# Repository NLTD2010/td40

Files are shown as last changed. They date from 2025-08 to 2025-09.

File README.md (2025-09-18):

# TD40



> **TD40** is a compact 40% mechanical keyboard designed for efficiency and portability.  
> It features **hot-swappable switches**, a **rotary knob**, an **OLED display**, **wireless connectivity**, and **per-key RGB lighting**.

---

## 🖼️ Preview

| TD40 (Back) | PCB |
|---|-----|
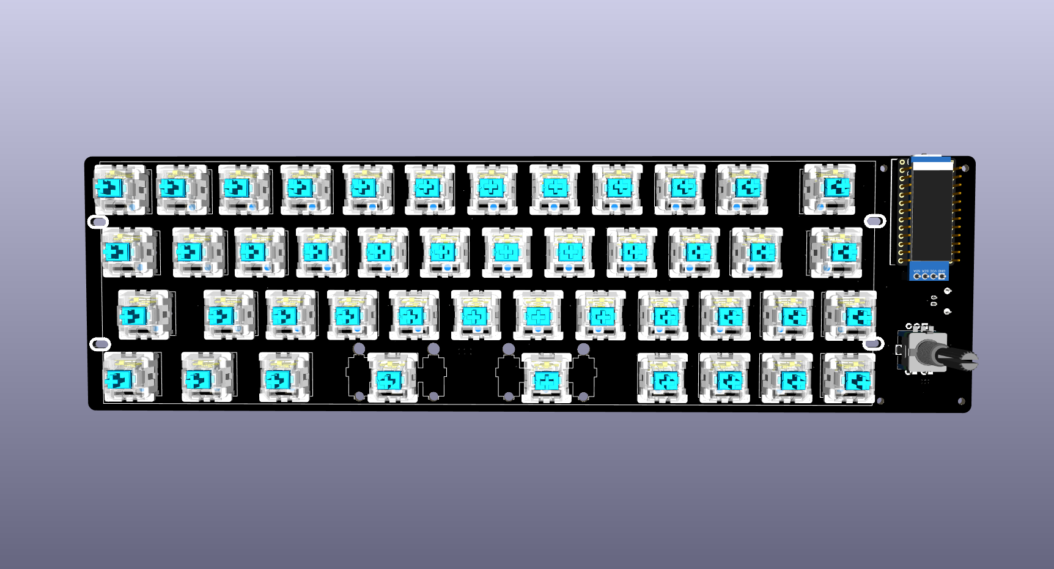
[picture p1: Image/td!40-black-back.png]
td40
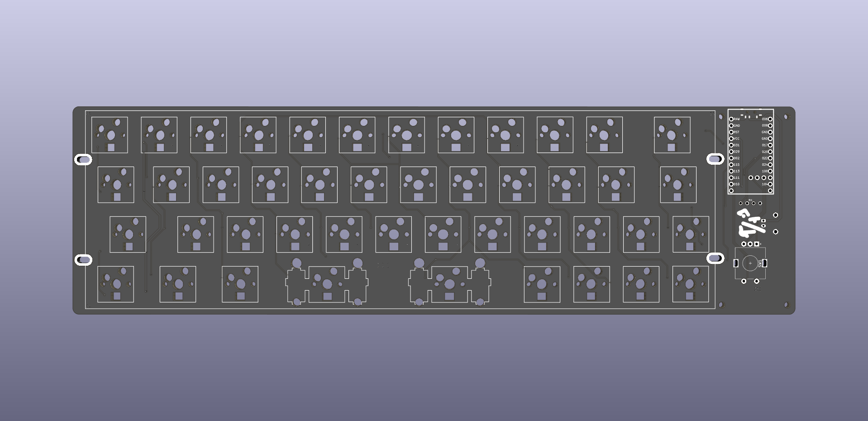
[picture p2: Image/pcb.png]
pcb
|  |  |

---

## ✨ Features
- Clean PCB design with **SMD soldering**
- **Nice!Nano v2** microcontroller – USB-C & Bluetooth compatible
- **Rotary encoder** + knob
- **0.91" OLED** screen
- **Per-key RGB** lighting
- **Hot-swappable** switches
- Open & visible components (Plaid / Romac style)
- Simple, flexible case options

---

## ⌨️ Layout
layout

---

## 📦 Bill of Materials

| # | Item | Qty |
|---|---|----:|
| 1 | PCB | 1 |
| 2 | FR4 plate | 1 |
| 3 | Mica case | 1 |
| 4 | Controller (**Nice!Nano v2**) | 1 |
| 5 | Switches (5-pin MX footprint)| 45 |
| 6 | Kailh hotswap socket | 45 |
| 7 | Diodes | 46 |
| 8 | Rotary encoder & knob | 1 |
| 9 | 0.91" OLED screen | 1 |

---

💡 **Tip:** Check out the [repository](https://github.com/NLTD2010/td40) for firmware, build guide, and more!

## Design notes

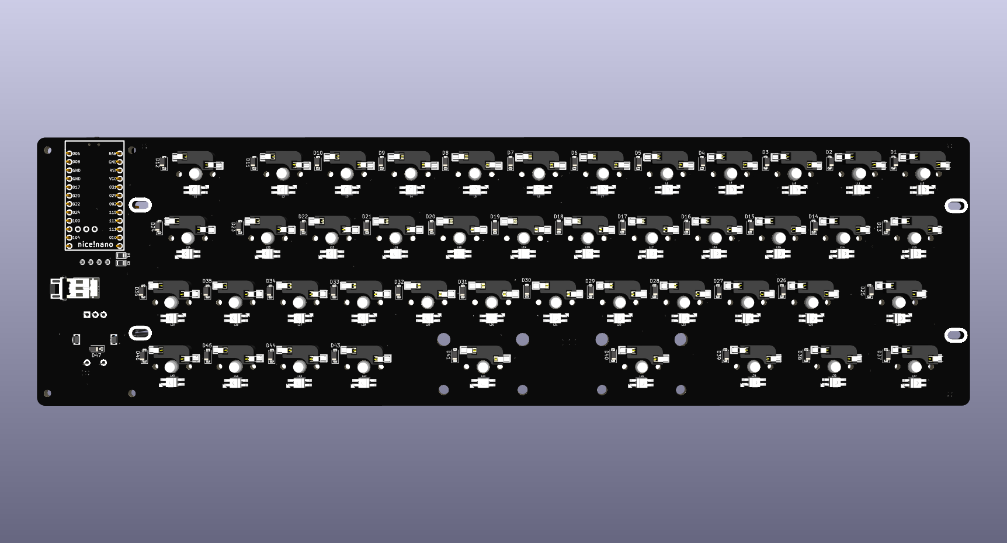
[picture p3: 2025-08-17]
Image/td!40-back-black.png

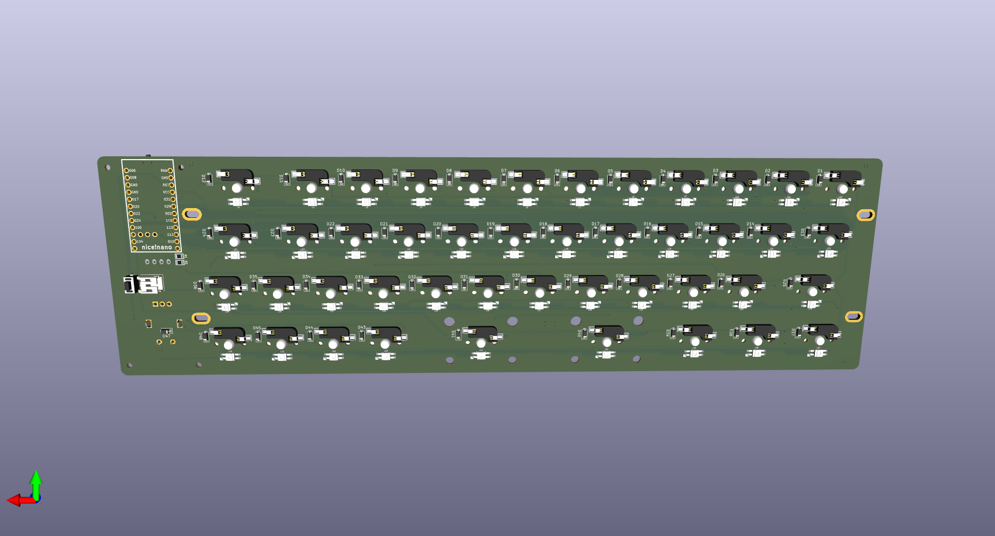
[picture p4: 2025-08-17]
Image/td!40_back.png

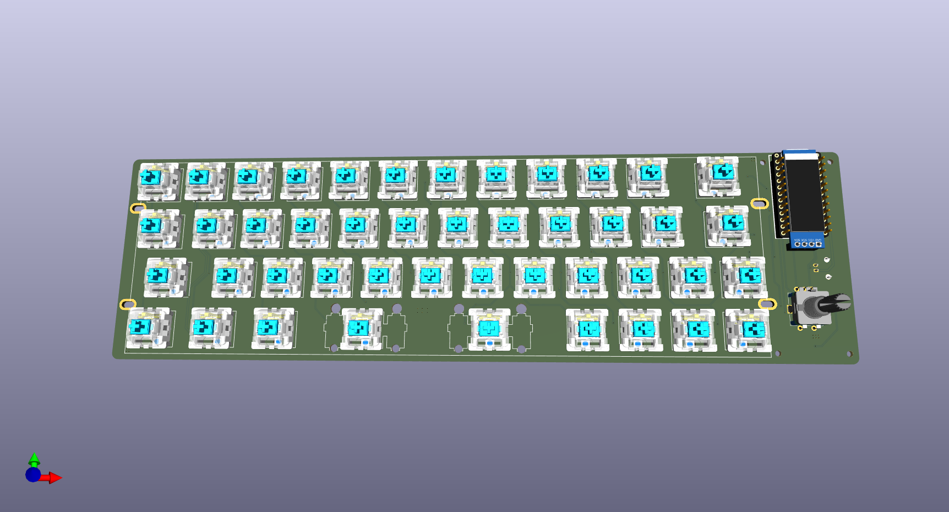
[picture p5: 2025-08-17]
Image/td!40.png

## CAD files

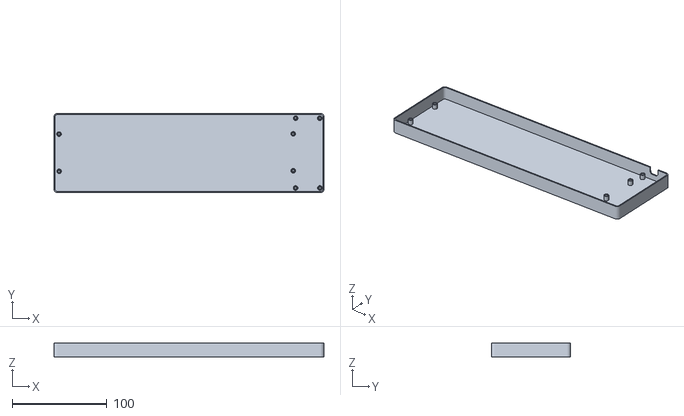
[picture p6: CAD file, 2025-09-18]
Case/case.stl
284.5 x 83.7 x 14.5

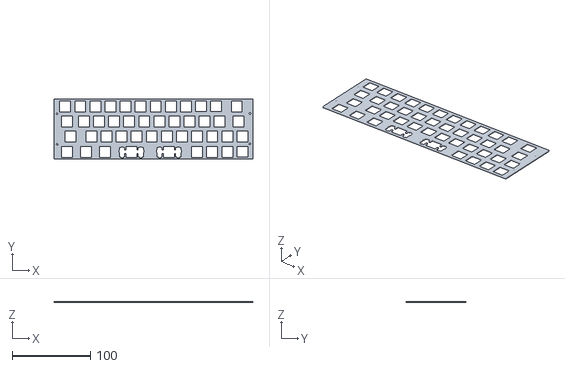
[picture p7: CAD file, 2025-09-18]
Case/plate.stl
254.5 x 76.9 x 1.51

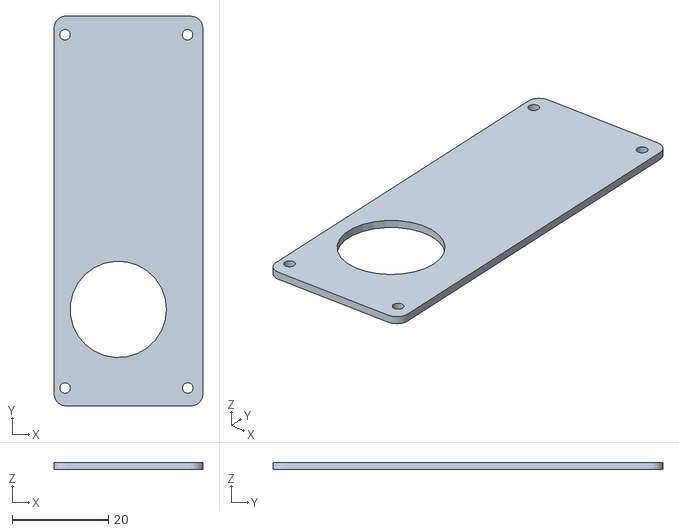
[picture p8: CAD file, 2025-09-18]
Case/cover.stl
31.0 x 81.2 x 1.51

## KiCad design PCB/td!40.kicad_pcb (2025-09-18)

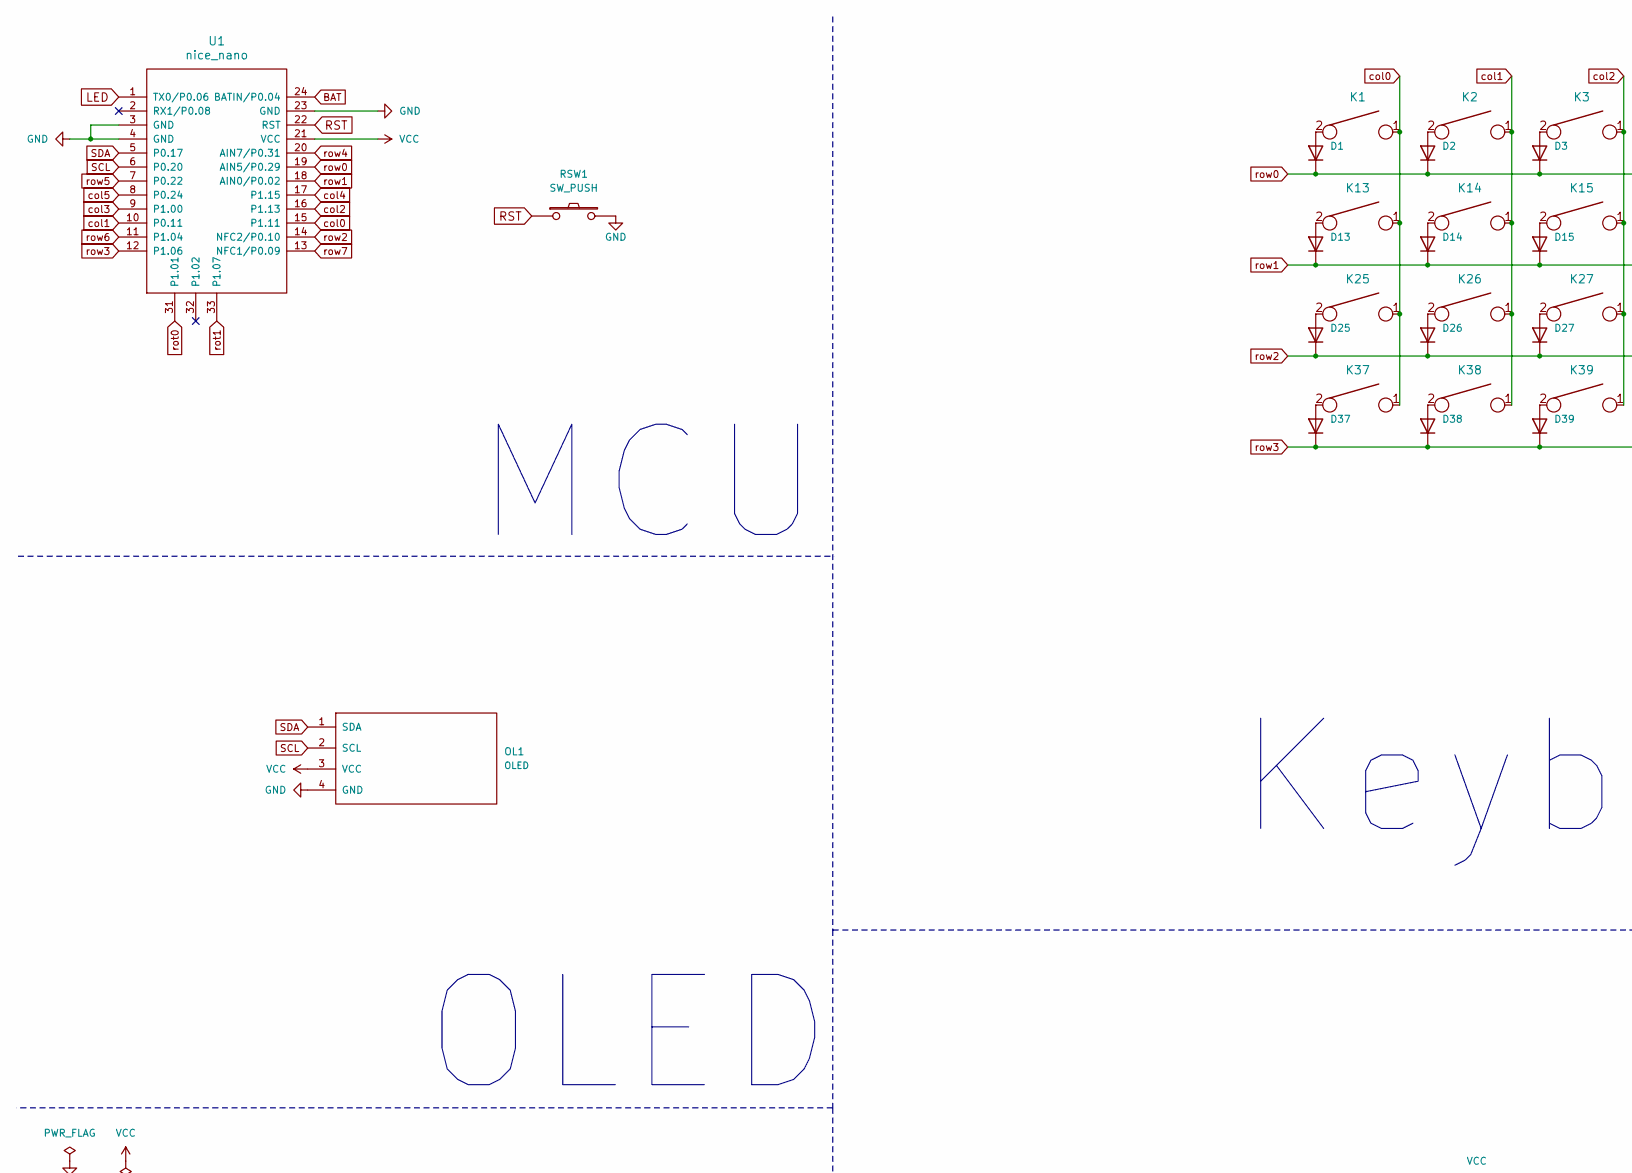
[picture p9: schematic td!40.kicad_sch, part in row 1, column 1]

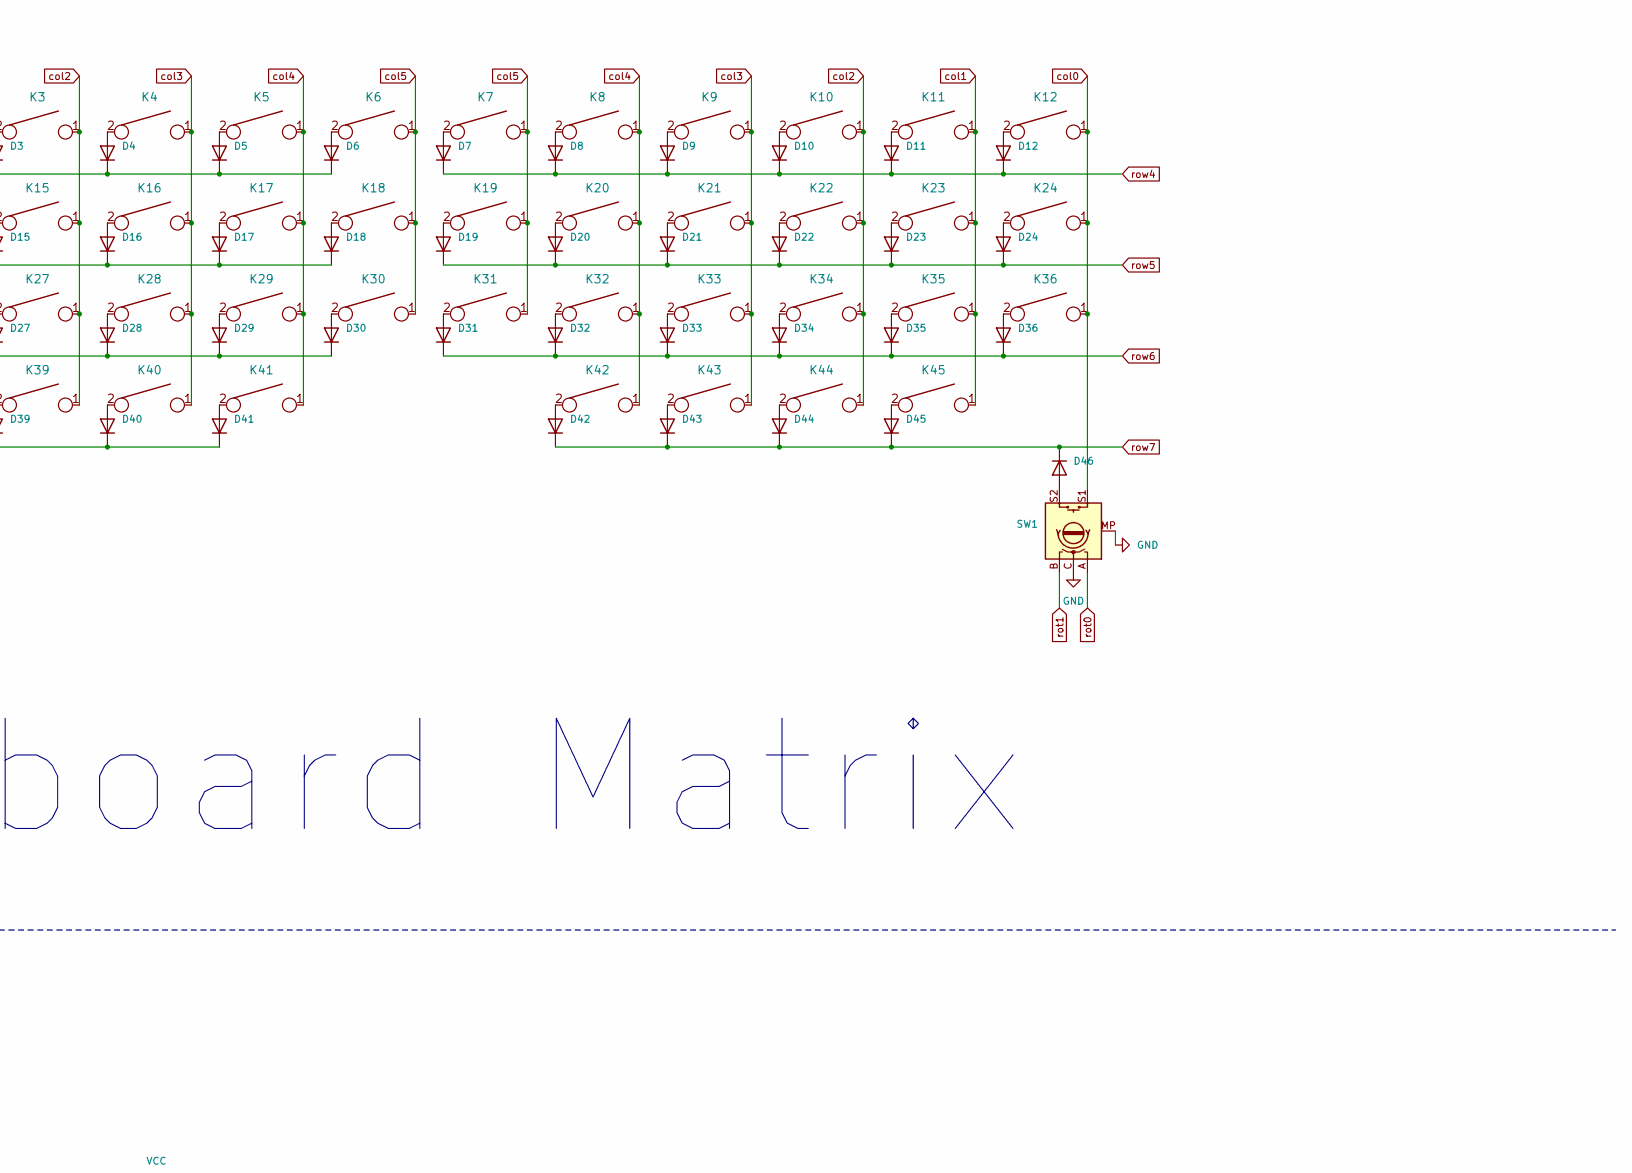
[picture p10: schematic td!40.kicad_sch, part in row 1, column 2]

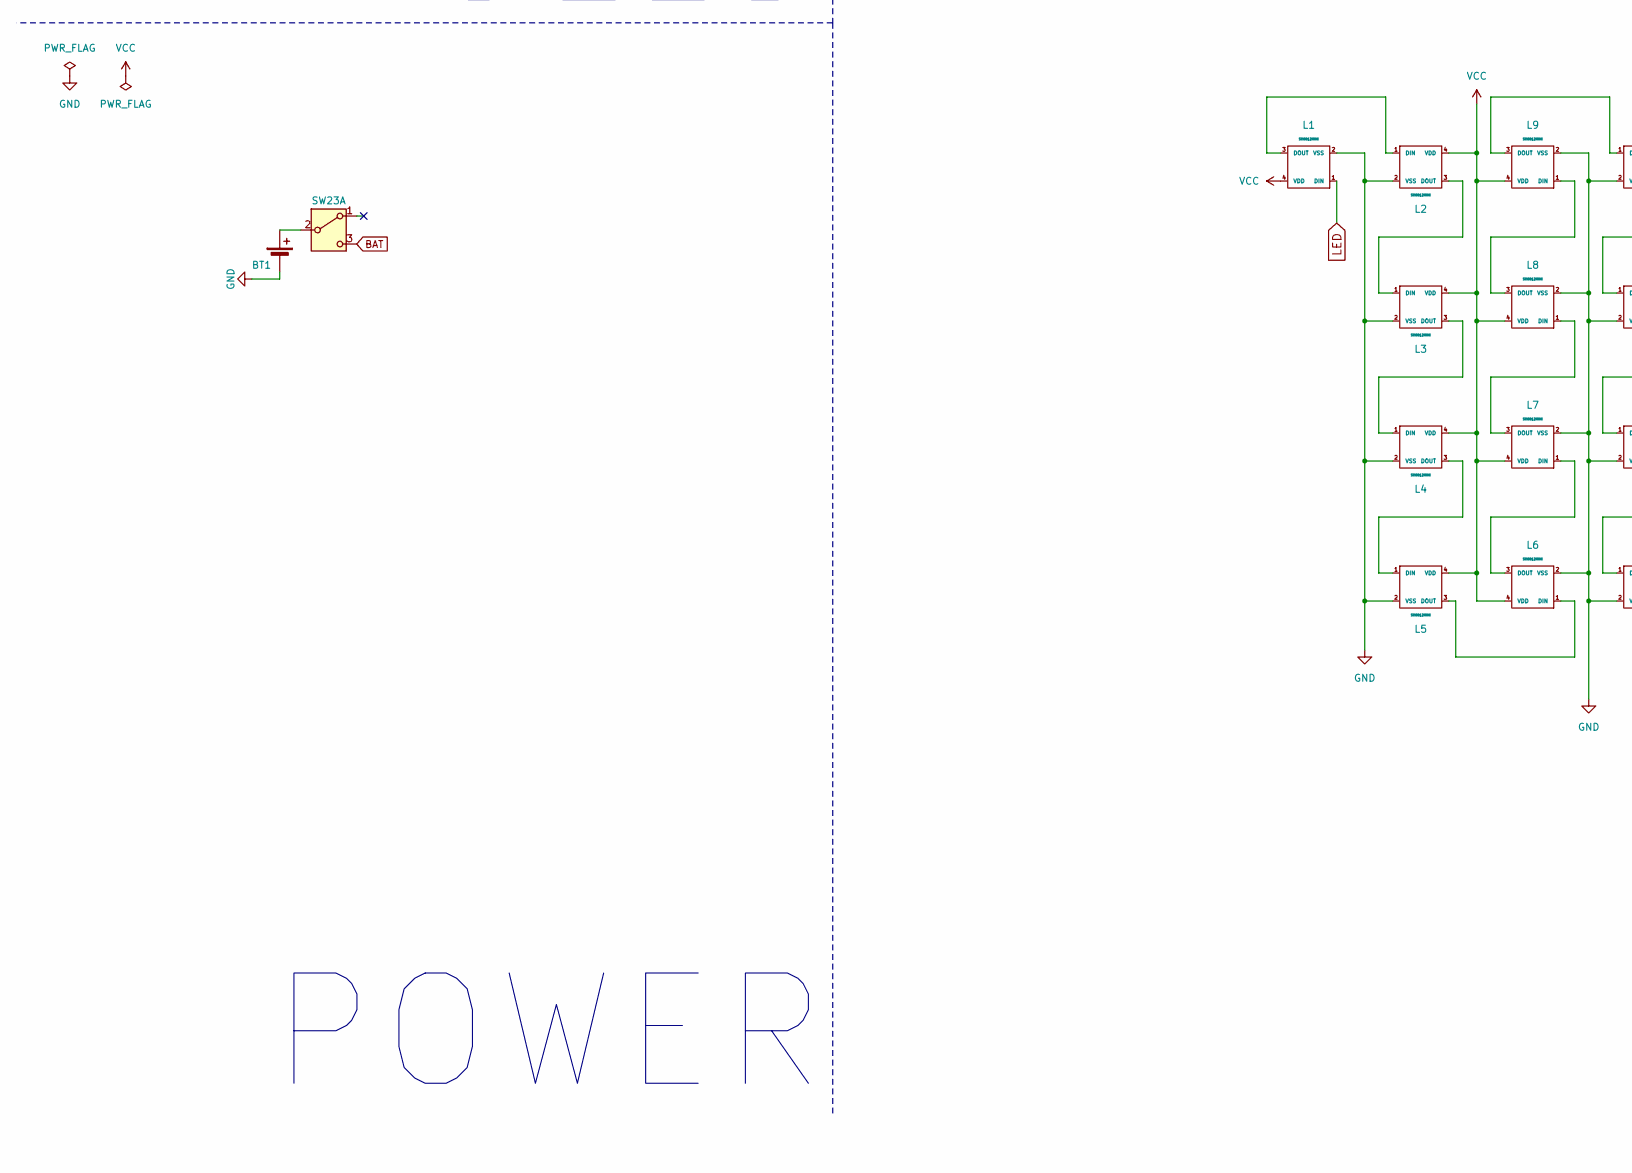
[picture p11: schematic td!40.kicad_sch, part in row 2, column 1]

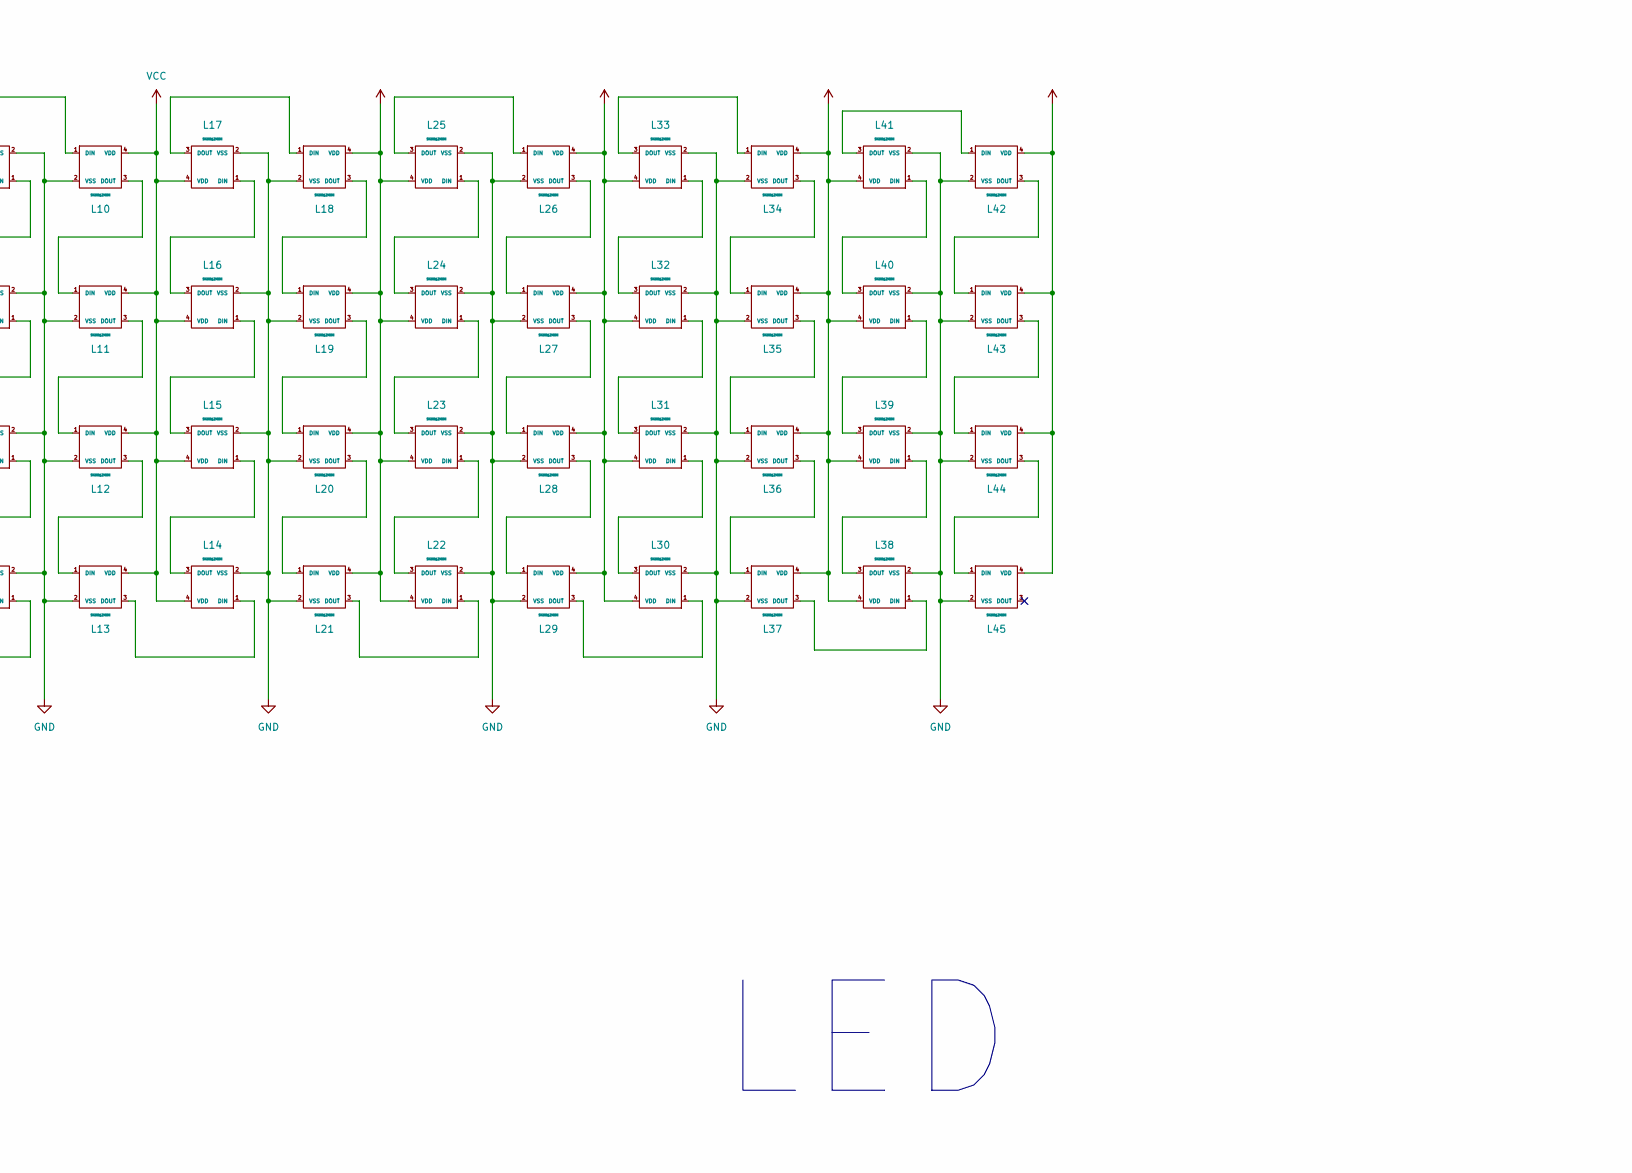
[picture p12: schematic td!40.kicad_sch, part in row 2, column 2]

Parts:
BT1: Battery_Cell; JST_PH_S2B-PH-K_1x02_P2.00mm_Horizontal_flipped
D1, D2, D3, D4, D5, D6, D7, D8, D9, D10, D11, D12, D13, D14, D15, D16, D17, D18, D19, D20, D21, D22, D23, D24, D25, D26, D27, D28, D29, D30, D31, D32, D33, D34, D35, D36, D37, D38, D39, D40, D41, D42, D43, D44, D45: D_SOD-123
D46: D; D_SOD-123
K1, K2, K3, K4, K5, K6, K7, K8, K9, K10, K11, K14, K15, K16, K17, K18, K19, K20, K21, K22, K23, K26, K27, K28, K29, K30, K31, K32, K33, K34, K35, K36, K42, K43, K44, K45: KEYSW; MX-Hotswap-1U
K12, K25: KEYSW; MX-Hotswap-1.75U
K13, K37, K38, K39: KEYSW; MX-Hotswap-1.25U
K24: KEYSW; MX-Hotswap-1.5U
K40: KEYSW; MX-Hotswap-2.25U-ReversedStabilizers
K41: KEYSW; MX-Hotswap-2.75U-ReversedStabilizers
L1, L2, L3, L4, L5, L6, L7, L8, L9, L10, L11, L12, L13, L14, L15, L16, L17, L18, L19, L20, L21, L22, L23, L24, L25, L26, L27, L28, L29, L30, L31, L32, L33, L34, L35, L36, L37, L38, L39, L40, L41, L42, L43, L44, L45: SK6812MINI; YS-SK6812MINI-E
OL1: OLED
RSW1: SW_PUSH; ResetSW
SW1: RotaryEncoder_Switch; RotaryEncoder_Alps_EC11E-Switch_Vertical_H20mm
SW23: SW23; switch-MSK-12C02-smd
U1: nice_nano

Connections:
BAT: SW23.3 (C), U1.24 (BATIN/P0.04)
GND: BT1.2 (-), L1.2 (VSS), L2.2 (VSS), L3.2 (VSS), L4.2 (VSS), L5.2 (VSS), L6.2 (VSS), L7.2 (VSS), L8.2 (VSS), L9.2 (VSS), L10.2 (VSS), L11.2 (VSS), L12.2 (VSS), L13.2 (VSS), L14.2 (VSS), L15.2 (VSS), L16.2 (VSS), L17.2 (VSS), L18.2 (VSS), L19.2 (VSS), L20.2 (VSS), L21.2 (VSS), L22.2 (VSS), L23.2 (VSS), L24.2 (VSS), L25.2 (VSS), L26.2 (VSS), L27.2 (VSS), L28.2 (VSS), L29.2 (VSS), L30.2 (VSS), L31.2 (VSS), L32.2 (VSS), L33.2 (VSS), L34.2 (VSS), L35.2 (VSS), L36.2 (VSS), L37.2 (VSS), L38.2 (VSS), L39.2 (VSS), L40.2 (VSS), L41.2 (VSS), L42.2 (VSS), L43.2 (VSS), L44.2 (VSS), L45.2 (VSS), OL1.4 (GND), RSW1.2, SW1.C, SW1.MP, U1.3 (GND), U1.4 (GND), U1.23 (GND)
LED: L1.1 (DIN), U1.1 (TX0/P0.06)
unnamed: BT1.1 (+), SW23.2 (B)
unnamed: D1.2 (A), K1.2
unnamed: D2.2 (A), K2.2
unnamed: D3.2 (A), K3.2
unnamed: D4.2 (A), K4.2
unnamed: D5.2 (A), K5.2
unnamed: D6.2 (A), K6.2
unnamed: D7.2 (A), K7.2
unnamed: D8.2 (A), K8.2
unnamed: D9.2 (A), K9.2
unnamed: D10.2 (A), K10.2
unnamed: D11.2 (A), K11.2
unnamed: D12.2 (A), K12.2
unnamed: D13.2 (A), K13.2
unnamed: D14.2 (A), K14.2
unnamed: D15.2 (A), K15.2
unnamed: D16.2 (A), K16.2
unnamed: D17.2 (A), K17.2
unnamed: D18.2 (A), K18.2
unnamed: D19.2 (A), K19.2
unnamed: D20.2 (A), K20.2
unnamed: D21.2 (A), K21.2
unnamed: D22.2 (A), K22.2
unnamed: D23.2 (A), K23.2
unnamed: D24.2 (A), K24.2
unnamed: D25.2 (A), K25.2
unnamed: D26.2 (A), K26.2
unnamed: D27.2 (A), K27.2
unnamed: D28.2 (A), K28.2
unnamed: D29.2 (A), K29.2
unnamed: D30.2 (A), K30.2
unnamed: D31.2 (A), K31.2
unnamed: D32.2 (A), K32.2
unnamed: D33.2 (A), K33.2
unnamed: D34.2 (A), K34.2
unnamed: D35.2 (A), K35.2
unnamed: D36.2 (A), K36.2
unnamed: D37.2 (A), K37.2
unnamed: D38.2 (A), K38.2
unnamed: D39.2 (A), K39.2
unnamed: D40.2 (A), K40.2
unnamed: D41.2 (A), K41.2
unnamed: D42.2 (A), K42.2
unnamed: D43.2 (A), K43.2
unnamed: D44.2 (A), K44.2
unnamed: D45.2 (A), K45.2
unnamed: D46.2 (A), SW1.S2
unnamed: L1.3 (DOUT), L2.1 (DIN)
unnamed: L2.3 (DOUT), L3.1 (DIN)
unnamed: L3.3 (DOUT), L4.1 (DIN)
unnamed: L4.3 (DOUT), L5.1 (DIN)
unnamed: L5.3 (DOUT), L6.1 (DIN)
unnamed: L6.3 (DOUT), L7.1 (DIN)
unnamed: L7.3 (DOUT), L8.1 (DIN)
unnamed: L8.3 (DOUT), L9.1 (DIN)
unnamed: L9.3 (DOUT), L10.1 (DIN)
unnamed: L10.3 (DOUT), L11.1 (DIN)
unnamed: L11.3 (DOUT), L12.1 (DIN)
unnamed: L12.3 (DOUT), L13.1 (DIN)
unnamed: L13.3 (DOUT), L14.1 (DIN)
unnamed: L14.3 (DOUT), L15.1 (DIN)
unnamed: L15.3 (DOUT), L16.1 (DIN)
unnamed: L16.3 (DOUT), L17.1 (DIN)
unnamed: L17.3 (DOUT), L18.1 (DIN)
unnamed: L18.3 (DOUT), L19.1 (DIN)
unnamed: L19.3 (DOUT), L20.1 (DIN)
unnamed: L20.3 (DOUT), L21.1 (DIN)
unnamed: L21.3 (DOUT), L22.1 (DIN)
unnamed: L22.3 (DOUT), L23.1 (DIN)
unnamed: L23.3 (DOUT), L24.1 (DIN)
unnamed: L24.3 (DOUT), L25.1 (DIN)
unnamed: L25.3 (DOUT), L26.1 (DIN)
unnamed: L26.3 (DOUT), L27.1 (DIN)
unnamed: L27.3 (DOUT), L28.1 (DIN)
unnamed: L28.3 (DOUT), L29.1 (DIN)
unnamed: L29.3 (DOUT), L30.1 (DIN)
unnamed: L30.3 (DOUT), L31.1 (DIN)
unnamed: L31.3 (DOUT), L32.1 (DIN)
unnamed: L32.3 (DOUT), L33.1 (DIN)
unnamed: L33.3 (DOUT), L34.1 (DIN)
unnamed: L34.3 (DOUT), L35.1 (DIN)
unnamed: L35.3 (DOUT), L36.1 (DIN)
unnamed: L36.3 (DOUT), L37.1 (DIN)
unnamed: L37.3 (DOUT), L38.1 (DIN)
unnamed: L38.3 (DOUT), L39.1 (DIN)
unnamed: L39.3 (DOUT), L40.1 (DIN)
unnamed: L40.3 (DOUT), L41.1 (DIN)
unnamed: L41.3 (DOUT), L42.1 (DIN)
unnamed: L42.3 (DOUT), L43.1 (DIN)
unnamed: L43.3 (DOUT), L44.1 (DIN)
unnamed: L44.3 (DOUT), L45.1 (DIN)
RST: RSW1.1, U1.22 (RST)
SCL: OL1.2 (SCL), U1.6 (P0.20)
SDA: OL1.1 (SDA), U1.5 (P0.17)
VCC: L1.4 (VDD), L2.4 (VDD), L3.4 (VDD), L4.4 (VDD), L5.4 (VDD), L6.4 (VDD), L7.4 (VDD), L8.4 (VDD), L9.4 (VDD), L10.4 (VDD), L11.4 (VDD), L12.4 (VDD), L13.4 (VDD), L14.4 (VDD), L15.4 (VDD), L16.4 (VDD), L17.4 (VDD), L18.4 (VDD), L19.4 (VDD), L20.4 (VDD), L21.4 (VDD), L22.4 (VDD), L23.4 (VDD), L24.4 (VDD), L25.4 (VDD), L26.4 (VDD), L27.4 (VDD), L28.4 (VDD), L29.4 (VDD), L30.4 (VDD), L31.4 (VDD), L32.4 (VDD), L33.4 (VDD), L34.4 (VDD), L35.4 (VDD), L36.4 (VDD), L37.4 (VDD), L38.4 (VDD), L39.4 (VDD), L40.4 (VDD), L41.4 (VDD), L42.4 (VDD), L43.4 (VDD), L44.4 (VDD), L45.4 (VDD), OL1.3 (VCC), U1.21 (VCC)
col0: K1.1, K12.1, K13.1, K24.1, K25.1, K36.1, K37.1, SW1.S1, U1.15 (P1.11)
col1: K2.1, K11.1, K14.1, K23.1, K26.1, K35.1, K38.1, K45.1, U1.10 (P0.11)
col2: K3.1, K10.1, K15.1, K22.1, K27.1, K34.1, K39.1, K44.1, U1.16 (P1.13)
col3: K4.1, K9.1, K16.1, K21.1, K28.1, K33.1, K40.1, K43.1, U1.9 (P1.00)
col4: K5.1, K8.1, K17.1, K20.1, K29.1, K32.1, K41.1, K42.1, U1.17 (P1.15)
col5: K6.1, K7.1, K18.1, K19.1, K30.1, K31.1, U1.8 (P0.24)
rot0: SW1.A, U1.31 (P1.01)
rot1: SW1.B, U1.33 (P1.07)
row0: D1.1 (K), D2.1 (K), D3.1 (K), D4.1 (K), D5.1 (K), D6.1 (K), U1.19 (AIN5/P0.29)
row1: D13.1 (K), D14.1 (K), D15.1 (K), D16.1 (K), D17.1 (K), D18.1 (K), U1.18 (AIN0/P0.02)
row2: D25.1 (K), D26.1 (K), D27.1 (K), D28.1 (K), D29.1 (K), D30.1 (K), U1.14 (NFC2/P0.10)
row3: D37.1 (K), D38.1 (K), D39.1 (K), D40.1 (K), D41.1 (K), U1.12 (P1.06)
row4: D7.1 (K), D8.1 (K), D9.1 (K), D10.1 (K), D11.1 (K), D12.1 (K), U1.20 (AIN7/P0.31)
row5: D19.1 (K), D20.1 (K), D21.1 (K), D22.1 (K), D23.1 (K), D24.1 (K), U1.7 (P0.22)
row6: D31.1 (K), D32.1 (K), D33.1 (K), D34.1 (K), D35.1 (K), D36.1 (K), U1.11 (P1.04)
row7: D42.1 (K), D43.1 (K), D44.1 (K), D45.1 (K), D46.1 (K), U1.13 (NFC1/P0.09)

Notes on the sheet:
LED
MCU
OLED
POWER
Keyboard Matrix

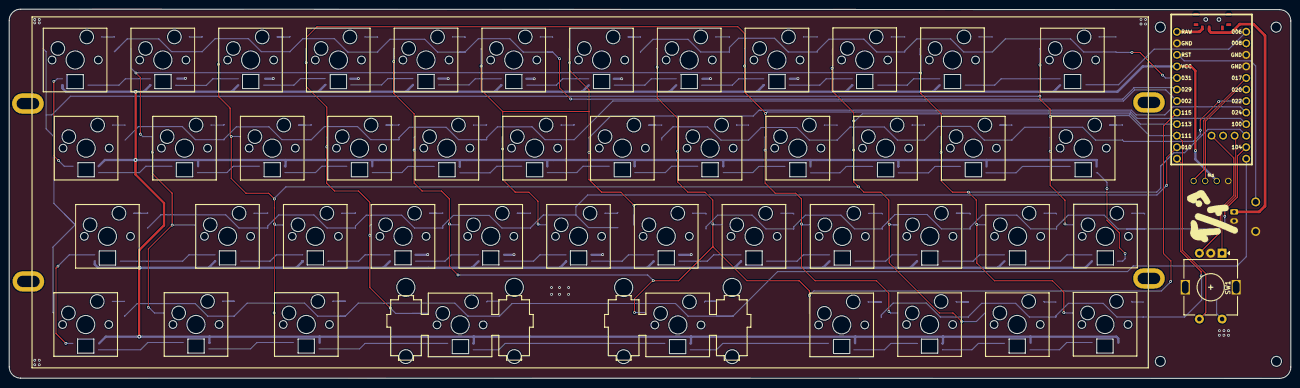
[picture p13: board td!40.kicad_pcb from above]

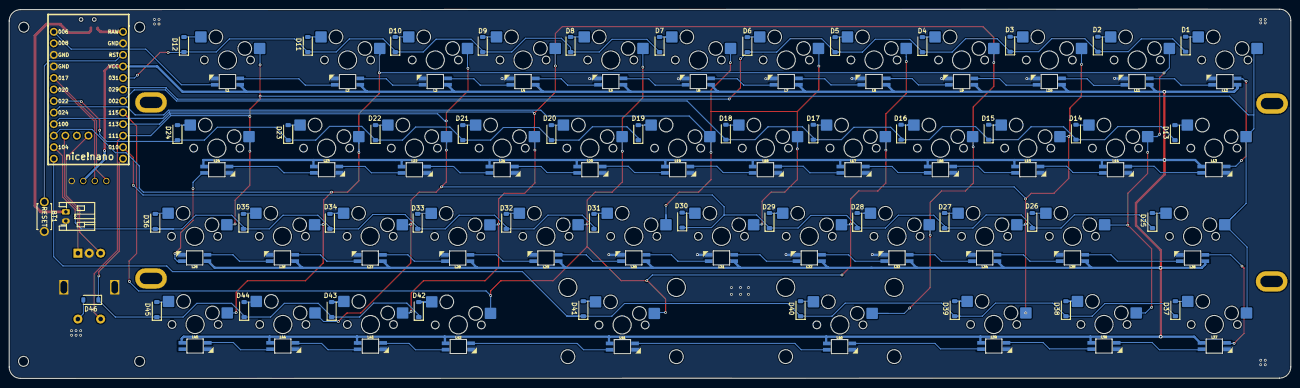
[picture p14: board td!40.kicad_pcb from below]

Board: 2 copper layers, 282.1 x 81.3 mm, 146 parts (139 on the bottom side), 114 nets.

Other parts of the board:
M1, M2, M3, M4: MountingHole_2.2mm_M2

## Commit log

2025-08-16 Add schematic and KLE layout
    [td!40.kicad_pcb, td!40.kicad_sch]
2025-08-17 PCB finished
    [td!40.kicad_pcb, td!40.kicad_sch]
2025-08-29 Update: No more DRC errors, yayy
    [td!40.kicad_pcb]
2025-09-18 Correct the RGB SK6812 pinout
    [td!40.kicad_pcb, td!40.kicad_sch]
2025-09-18 Add README.md, 3D models and images
    [case.stl, cover.stl, plate.stl]
